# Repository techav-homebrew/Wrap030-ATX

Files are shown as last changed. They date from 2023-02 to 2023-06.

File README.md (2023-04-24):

# Wrap030
Homebrew mATX form-factor 68030 computer

# Memory Map

## Normal Operation
This is the space allocated to each device (even if the device will not use the entire address space allocated, such as the PS/2 keyboard controller which uses no address lines). 

| Device | Start | End | Size |
| --- | --- | --- | --- |
| Main Memory | `$0000,0000`  | `$7fff,ffff`  | 2048MB (256MB available)  |
| Unused (BERR) | `$8000,0000`  | `$cfff,ffff`  | 1280MB |
| Video | `$d000,0000`  | `$d0ff,ffff`  | 16MB |
| Unused (BERR) | `$d100,0000`  | `$d1ff,ffff`  | 16MB |
| ISA Memory | `$d200,0000`  | `$d2ff,ffff`  | 16MB |
| ISA I/O | `$d300,0000`  | `$d3ff,ffff`  | 16MB |
| Unused (BERR) | `$d400,0000`  | `$dbff,ffff`  |  128MB |
| S/P I/O | `$dc00,0000`  | `$dcff,ffff`  | 16MB |
| Reserved (BERR) | `$dd00,0000`  | `$ddff,ffff`  | 16MB |
| Keyboard | `$de00,0000`  | `$deff,ffff`  | 16MB |
| Reserved (BERR) | `$df00,0000`  | `$dfff,ffff`  | 16MB |
| Bus Ctrl Reg | `$e000,0000`  | `$e0ff,ffff`  | 16MB |
| DRAM Ctrl Reg | `$e100,0000`  | `$e1ff,ffff`  | 16MB |
| IRQ Ctrl Reg | `$e200,0000`  | `$e2ff,ffff`  | 16MB |
| Unused (BERR) | `$e300,0000`  | `$efff,ffff`  |  208MB |
| ROM | `$f000,0000`  | `$ffff,ffff`  |  256MB |

## Reset Overlay
The reset overlay allows ROM to be read from the first 256MB of the CPU address space so the CPU can load the proper startup vectors. While the reset overlay is enabled, DRAM is write-only through the first 256MB (the entire DRAM space available on the Wrap030-ATX board). ROM will continue to be readable in its normal address space. This allows the reset vector to point to ROM at its normal address.

The reset overlay is enabled by default on power on. It is disabled by setting the overlay bit on the bus controller register. 

| Device | Start | End | Notes |
| --- | --- | --- | --- |
| ROM Overlay | `$0000,0000`  | `$0fff,ffff`  | Read-only 256MB ROM space |
| DRAM Overlay | `$0000,0000`  | `$0fff,ffff`  | Write-Only 256MB DRAM space |
| DRAM | `$1000,0000`  | `$7fff,ffff`  | Read/Write DRAM space |
| ROM | `$f000,0000`  | `$ffff,ffff`  | Read/Write ROM space |

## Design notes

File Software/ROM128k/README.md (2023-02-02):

This will be a collection of 68k assembly files pulled together to make a single 128kB ROM. Making use of a makefile & linker script to make it easier to build.

## Contents:
1. Reset Vectors
2. TSMON ROM Monitor
3. TSMON Expansion ROM
4. 68k Enhanced BASIC (w/FPU support)

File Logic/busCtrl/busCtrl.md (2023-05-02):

# Wrap030-ATX Bus Controller

## Bus Controller Feature Description

The bus controller handles decoding the CPU Function Codes and Address bus to activate system memory and peripherals. For devices which do not produce their own bus cycle acknowledge signals, it handles timing & wait state generation and produces the appropriate cycle termination signals. It also receives incoming cycle termination signals from other bus devices and reproduces them for the CPU, meeting setup timing requirements. The bus controller generates a bus error for invalid accesses, missing FPU, and bus cycles which time out with no other external device providing an appropriate termination. It will also assert the CPU's cache inhibit signal for peripheral accesses which should not be cached. 

On initial power on, the bus controller will pull the power supply's power on signal low and hold it until the soft power bit in the bus controller register is cleared. 

The bus controller has an internal register accessible at address `$e000,0000` which holds the startup overlay enable bit, soft power control bit, and a general-purpose output for driving an LED.

## Bus Controller Cycles

- DRAM
  - Asserts the RAM chip enable signal and waits for the memory controller to assert its cycle ackowledge signal. 
- ROM
  - Asserts the ROM chip enable signal and the appropriate memory read or write strobe. Inserts wait states for a 70ns ROM and terminates bus cycle.
- Video Controller
  - Asserts the video chip enable signal and waits for the video generator to assert its cycle acknowledge signal.
- ISA
  - Asserts the ISA chip enable signal and waits for the ISA bus controlelr to assert the appropriate 8-bit or 16-bit cycle acknowledge signal.
- Serial/Parallel I/O
  - Asserts the SPIO chip enable signal and the appropriate memory read or write strobe. Inserts wait states for WD16C552 and terminates bus cycle.
- Keyboard Controller
  - Asserts the keyboard controller chip enable signal and waits for the keyboard controller to assert its cycle acknowledge signal.
- DRAM Controller
  - If startup overlay bit is clear:
    - Asserts the DRAM controller chip enable signal and waits for the DRAM controller to assert its cycle acknowledge signal.
  - If startup overlay bit is set:
    - Generates a bus error.
- Bus Controller
  - Reads or writes the bus controller register as appropriate and terminates the bus cycle.
- Interrupt Controller
  - Asserts the interrupt controller chip enable signal and waits for the interrupt controller to assert its cycle acknowledge signal.

## Bus Controller Settings Register
0. Startup Overlay
   - **SET**: Disable startup overlay
   - **CLEAR**: Enable startup overlay
1. Soft Power
   - **SET**: Power down
   - **CLEAR**: Normal operation
2. GPO LED
   - **SET**: LED on
   - **CLEAR**: LED off
3. (future use)
4. (future use)
5. (future use)
6. (future use)
7. (future use)

## Bus Controller State Machine

```mermaid
---
Bus Controller State Machine
---
stateDiagram-v2
    state "Idle" as sIDL
    state idleChoice <<fork>>
    state endFork <<fork>>
    state memChoice <<choice>>

    state "ROM 0" as sROM0
    state "ROM 1" as sROM1
    state "ROM 2" as sROM2
    state "ROM 3" as sROM3
    state "ROM Cycle" as sROM

    state "S/P I/O 0" as sSPIO0
    state "S/P I/O 1" as sSPIO1
    state "S/P I/O 2" as sSPIO2
    state "S/P I/O 3" as sSPIO3
    state "S/P I/O 4" as sSPIO4
    state "S/P I/O 5" as sSPIO5
    state "S/P I/O 6" as sSPIO6
    state "S/P I/O Cycle" as sSPIO

    state "DRAM Hold" as sDRAM0
    state "DRAM Access Cycle" as sDRAM

    state "FPU Start" as sFPU0
    state "FPU Term" as sFPU1
    state "FPU Access Cycle" as sFPU

    state "VidGen Start" as sVID0
    state "VidGen Term" as sVID1
    state "VidGen Access Cycle" as sVID

    state "Keyboard Start" as sKBD0
    state "Keyboard Term" as sKBD1
    state "Keyboard Access Cycle" as sKBD

    state "ISA Start" as sISA0
    state "ISA Term" as sISA1
    state "ISA Access Cycle" as sISA

    state "busCtrl Register Read" as sREGR
    state "busCtrl Register Write" as sREGW
    state regChoice <<choice>>
    state "busCtrl Register Cycle" as sREG
    
    state "IRQ Autovector" as sAVEC

    [*] --> sIDL: sysRESETn = 0
    sIDL --> idleChoice
    idleChoice --> sSPIO
    idleChoice --> sFPU
    idleChoice --> sVID
    idleChoice --> sKBD
    idleChoice --> sISA
    idleChoice --> memChoice
    idleChoice --> sREG
    idleChoice --> sAVEC

    sAVEC --> endFork

    state sREG {
        [*] --> regChoice
        regChoice --> sREGR: cpuRWn = 1
        regChoice --> sREGW: cpuRWn = 0
        sREGR --> [*]
        sREGW --> [*]
    }
    sREG --> endFork

    memChoice --> sDRAM: (overlay = 1 & cpuAddrHi = $00)
    memChoice --> sROM: ((overlay = 0 & cpuAddrHi = $00) | (overlay = 1 & cpuAddrHi = $f0))

    state sISA {
        [*] --> sISA0
        sISA0 --> sISA0: isaACK8n = 1 & isaACK16n = 1
        sISA0 --> sISA1
        sISA1 --> [*]
    }
    sISA --> endFork

    state sKBD {
        [*] --> sKBD0
        sKBD0 --> sKBD0: kbdACKn = 1
        sKBD0 --> sKBD1: kbdACKn = 0
        sKBD1 --> [*]
    }
    sKBD --> endFork

    state sVID {
        [*] --> sVID0
        sVID0 --> sVID0: vidACKn = 1
        sVID0 --> sVID1: vidACKn = 0
        sVID1 --> [*]
    }
    sVID --> endFork
    
    state sDRAM {
        [*] --> sDRAM0
        sDRAM0 --> sDRAM0: ramACKn = 1
        sDRAM0 --> [*]: ramACKn = 0
    }
    sDRAM --> endFork

    state sFPU {
        [*] --> sFPU0
        sFPU0 --> sFPU0: busACKn[0] = 1 & busACKn[1] = 1
        sFPU0 --> sFPU1
        sFPU1 --> [*]
    }
    sFPU --> endFork

    state sROM {
        [*] --> sROM0
        sROM0 --> sROM1
        sROM1 --> sROM2
        sROM2 --> sROM3
        sROM3 --> [*]
    }
    sROM --> endFork

    state sSPIO {
        [*] --> sSPIO0
        sSPIO0 --> sSPIO1
        sSPIO1 --> sSPIO2
        sSPIO2 --> sSPIO3
        sSPIO3 --> sSPIO4
        sSPIO4 --> sSPIO5
        sSPIO5 --> sSPIO6
        sSPIO6 --> [*]
    }
    sSPIO --> endFork
```

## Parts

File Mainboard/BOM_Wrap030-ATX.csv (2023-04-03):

Reference | Value | Footprint | Datasheet | JLC-Part | Mouser-Part | Notes | Sim.Device | Sim.Pins | Socket-Mouser | Qty
SW1 | SW_Push | Button_Switch_THT:SW_PUSH_6mm | ~ |  | 179-TS026660BK260LCR | OFE |  |  |  | 1
C1-C12, C14, C16, C17, C20-C39, C43-C50, C52-C63, C66, C68-C70, C76-C82, C88-C91, C101, C110, C112-C117 | 100nF | Capacitor_SMD:C_0402_1005Metric_Pad0.74x0.62mm_HandSolder | ~ | https://jlcpcb.com/partdetail/1877-CL05B104KO5NNNC/C1525 | 187-CL05B104KO5NNNC | JLC |  |  |  | 78
C13, C15, C18, C19, C40-C42, C51, C64, C65, C67, C92, C111 | 1uF | Capacitor_SMD:C_0402_1005Metric_Pad0.74x0.62mm_HandSolder | ~ | https://jlcpcb.com/partdetail/53938-CL05A105KA5NQNC/C52923 | 187-CL05A105KA5NQNC | JLC |  |  |  | 13
C93-C100 | 2200pF | Capacitor_SMD:C_0402_1005Metric_Pad0.74x0.62mm_HandSolder | ~ | https://jlcpcb.com/partdetail/1883-0402B222K500NT/C1531 | 81-GRM155R71H222KA1J | JLC |  |  |  | 8
C71, C73, C75, C84, C86 | 10uF | Capacitor_THT:CP_Radial_D5.0mm_P2.50mm | ~ |  | 710-860010372001 | OFE |  |  |  | 5
C72, C74, C83, C85, C87 | 100uF | Capacitor_THT:CP_Radial_D7.5mm_P2.50mm | ~ |  | 710-860010473007 | OFE |  |  |  | 5
P1 | AT-P8 | Connector_Molex:Molex_KK-396_A-41791-0006_1x06_P3.96mm_Vertical | ~ |  | 538-26-60-4060 | OFE |  |  |  | 1
P2 | AT-P9 | Connector_Molex:Molex_KK-396_A-41791-0006_1x06_P3.96mm_Vertical | ~ |  | 538-26-60-4060 | OFE |  |  |  | 1
J8 | ATX-24 | Connector_Molex:Molex_Mini-Fit_Jr_5566-24A_2x12_P4.20mm_Vertical | https://www.intel.com/content/dam/www/public/us/en/documents/guides/power-supply-design-guide-june.pdf |  | 538-39-28-8240 |  |  |  |  | 1
J7 | POWER | Connector_PinHeader_2.54mm:PinHeader_1x02_P2.54mm_Vertical | ~ |  | 523-G800NA306018EU | OFE |  |  |  | 1
J9 | RESET | Connector_PinHeader_2.54mm:PinHeader_1x02_P2.54mm_Vertical | ~ |  | 523-G800NA306018EU | OFE |  |  |  | 1
J2 | FPU CLK | Connector_PinHeader_2.54mm:PinHeader_1x03_P2.54mm_Vertical | ~ |  | 523-G800W305018EU | OFE |  |  |  | 1
J10 | BIDEN | Connector_PinHeader_2.54mm:PinHeader_1x03_P2.54mm_Vertical | ~ |  | 523-G800W305018EU | OFE |  |  |  | 1
IDE0 | Conn_02x20_Odd_Even | Connector_PinHeader_2.54mm:PinHeader_2x20_P2.54mm_Vertical | ~ |  | 710-61203921621 | OFE |  |  |  | 1
Y1 | 16M | Crystal:Resonator-3Pin_W7.0mm_H2.5mm | ~ |  | 81-CSTLS16M0X55-B0 | Mouser |  |  |  | 1
D9, D10 | 1N4148W | Diode_SMD:D_SOD-123 |  | https://jlcpcb.com/partdetail/st_semtech-1N4148W/C81598 | 833-1N4148W-TP | JLC | D | 1=K 2=A |  | 2
FID1-FID3 | Fiducial | Fiducial:Fiducial_1mm_Mask2mm | ~ |  |  | NA |  |  |  | 3
D1-D8 | LED | LED_THT:LED_D3.0mm | ~ |  | 859-LTL1CHJETNN | OFE |  |  |  | 8
H1-H9 | 4mm | MountingHole:MountingHole_4mm_Pad_Via | ~ |  |  | NA |  |  |  | 9
X1 | 50M | Oscillator:Oscillator_DIP-8 | http://cdn-reichelt.de/documents/datenblatt/B400/OSZI.pdf |  | 815-ACH-50-EK | Mouser |  |  |  | 1
X2 | 25.175M | Oscillator:Oscillator_DIP-8 | http://cdn-reichelt.de/documents/datenblatt/B400/OSZI.pdf |  | 774-MXO45HS-3C-25.1 | Mouser |  |  |  | 1
X3 | 16M | Oscillator:Oscillator_DIP-8 | http://cdn-reichelt.de/documents/datenblatt/B400/OSZI.pdf |  | 815-ACH-16-EK | Mouser |  |  |  | 1
X4 | 1.8432M | Oscillator:Oscillator_DIP-8 | http://cdn-reichelt.de/documents/datenblatt/B400/OSZI.pdf |  | 520-TCH184-X | Mouser |  |  |  | 1
X5 | 14.3181M | Oscillator:Oscillator_DIP-8 | http://cdn-reichelt.de/documents/datenblatt/B400/OSZI.pdf |  | ECS-2100AX-14.31818MHZ | Mouser |  |  |  | 1
U3 | 74ACT04 | Package_DIP:DIP-14_W7.62mm_Socket | https://assets.nexperia.com/documents/data-sheet/74HC_HCT04.pdf |  | 595-SN74ACT04N | OFE |  |  | 571-1-2199298-3 | 1
U19 | 74ACT139 | Package_DIP:DIP-16_W7.62mm_Socket | http://www.ti.com/lit/ds/symlink/sn74ls139a.pdf |  | 595-CD74ACT139E | OFE |  |  | 571-1-2199298-4 | 1
U24 | ATtiny2313A | Package_DIP:DIP-20_W7.62mm | http://ww1.microchip.com/downloads/en/DeviceDoc/Atmel-2543-AVR-ATtiny2313_Datasheet.pdf |  | 556-ATTINY2313A-PU | Mouser |  |  | 571-1-2199298-6 | 1
U4-U7, U10-U12, U16 | 74ACT245 | Package_DIP:DIP-20_W7.62mm_Socket | http://www.ti.com/lit/gpn/sn74HC245 |  | 595-SN74ACT245N | OFE |  |  | 571-1-2199298-6 | 8
U13-U15 | 74ACT573 | Package_DIP:DIP-20_W7.62mm_Socket | 74xx/74hc573.pdf |  | 595-SN74ACT573N | OFE |  |  | 571-1-2199298-6 | 3
U18 | 74HCT688 | Package_DIP:DIP-20_W7.62mm_Socket | https://www.ti.com/lit/ds/symlink/cd54hc688.pdf |  | 595-CD74HCT688EE4 | OFE |  |  | 571-1-2199298-6 | 1
VRAM1, VRAM2 | CY62256-70PC | Package_DIP:DIP-28_W7.62mm_Socket | https://ecee.colorado.edu/~mcclurel/Cypress_SRAM_CY62256.pdf |  | 972-71256SA15TPG | OFE |  |  | 571-1-2199298-9 | 2
ROM1 | 39SF040 | Package_LCC:PLCC-32_THT-Socket | http://ww1.microchip.com/downloads/en/DeviceDoc/25022B.pdf |  | 804-39SF0407CNHE | OFE |  |  | 575-943224 | 1
U17 | ATF1504AS | Package_LCC:PLCC-44_THT-Socket |  |  | 556-AF1500A10JU | OFE |  |  | 151-1545 | 1
U20 | WD16C552 | Package_LCC:PLCC-68_THT-Socket |  |  | 595-TL16C552AIFN | OFE |  |  | 575-682444 | 1
GLUE1 | ATF1508AS | Package_LCC:PLCC-84_THT-Socket |  |  | 556-ATF1508AS-10JU84 | OFE |  |  | 575-948424 | 1
RAMC1 | ATF1508AS | Package_LCC:PLCC-84_THT-Socket |  |  | 556-ATF1508AS-10JU84 | OFE |  |  | 575-948424 | 1
U32 | ATF1508AS | Package_LCC:PLCC-84_THT-Socket |  |  | 556-ATF1508AS-10JU84 | OFE |  |  | 575-948424 | 1
VGEN1 | ATF1508AS | Package_LCC:PLCC-84_THT-Socket |  |  | 556-ATF1508AS-10JU84 | OFE |  |  | 575-948424 | 1
VBUF1 | ADA4891-4 | Package_SO:SOIC-14_3.9x8.7mm_P1.27mm |  |  | 584-ADA4891-4ARZ | Mouser |  |  |  | 1
U21, U23 | GD65232 | Package_SO:TSSOP-20_4.4x6.5mm_P0.65mm | http://www.ti.com/lit/ds/symlink/gd75232.pdf |  | 595-GD65232PWR | Mouser |  |  |  | 2
U9 | DS1813 | Package_TO_SOT_THT:TO-92_Inline |  |  | 700-DS1813-5T&R | OFE |  |  |  | 1
Q1 | PN2222A | Package_TO_SOT_THT:TO-92L_Inline | ~ |  | 512-PN2222ABU | OFE |  |  |  | 1
R1-R3 | 10k | Resistor_SMD:R_0402_1005Metric_Pad0.72x0.64mm_HandSolder | ~ | https://jlcpcb.com/partdetail/26487-0402WGF1002TCE/C25744 | 303-0402WGF1002TCE | JLC |  |  |  | 3
R4-R12 | 220R | Resistor_SMD:R_0402_1005Metric_Pad0.72x0.64mm_HandSolder | ~ | https://jlcpcb.com/partdetail/25834-0402WGF2200TCE/C25091 | 303-0402WGF2200TCE | JLC |  |  |  | 9
R13-R30, R52-R75 | 1k | Resistor_SMD:R_0402_1005Metric_Pad0.72x0.64mm_HandSolder | ~ | https://jlcpcb.com/partdetail/12256-0402WGF1001TCE/C11702 | 303-0402WGF1001TCE | JLC |  |  |  | 42
R76-R79 | 75R | Resistor_SMD:R_0402_1005Metric_Pad0.72x0.64mm_HandSolder | ~ | https://jlcpcb.com/partdetail/25876-0402WGF750JTCE/C25133 | 303-0402WGF750JTCE | JLC |  |  |  | 4
R31-R51 | 33R | Resistor_SMD:R_0603_1608Metric_Pad0.98x0.95mm_HandSolder | ~ | https://jlcpcb.com/partdetail/23867-0603WAF330JT5E/C23140 | 303-0603WAF330JT5E | JLC |  |  |  | 21
J3 | DE15_Receptacle_HighDensity_MountingHoles | Wrap030-ATX:DE15-HD | https://www.mouser.com/datasheet/2/123/4/EDAC_633_634_Series_D_sub_Connectors_English_Order-2498032.pdf |  | 587-634-015-263-030 | Mouser |  |  |  | 1
J4-J6 | Bus_ISA_16bit | Wrap030-ATX:ISA16 | https://en.wikipedia.org/wiki/Industry_Standard_Architecture |  | 571-5645169-4 | eBay |  |  |  | 3
J14 | L17H26R0121 | Wrap030-ATX:L17H26R0121 |  |  | 523-L17H26R0121 | Mouser |  |  |  | 1
J13 | mDIN-6 | Wrap030-ATX:MiniDIN6 | https://www.te.com/commerce/DocumentDelivery/DDEController?Action=srchrtrv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 |  | 571-5749266-1 | Mouser |  |  |  | 1
U1 | MC68882 | Wrap030-ATX:PGA68 |  |  |  | Mouser |  |  | 437-5108306810061101 | 1
CPU1 | MC68030 | Wrap030-ATX:PGA128 |  |  |  | OFE |  |  | 437-5108712813041101 | 1
U2, U8 | TE-822021-4 | Wrap030-ATX:SIMM72 |  |  | 571-5822021-4 | OFE |  |  |  | 2

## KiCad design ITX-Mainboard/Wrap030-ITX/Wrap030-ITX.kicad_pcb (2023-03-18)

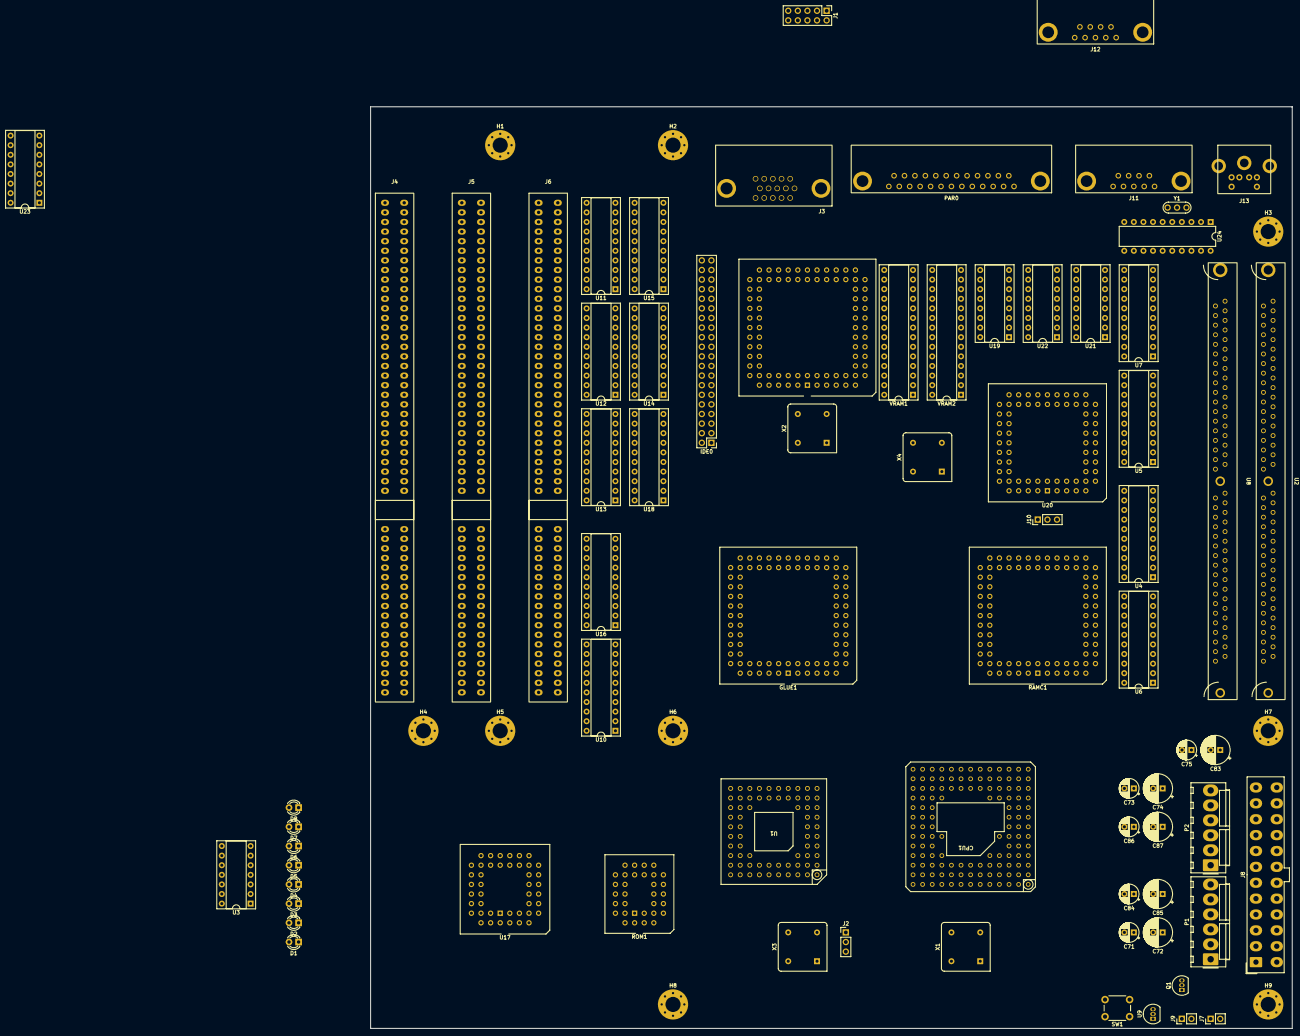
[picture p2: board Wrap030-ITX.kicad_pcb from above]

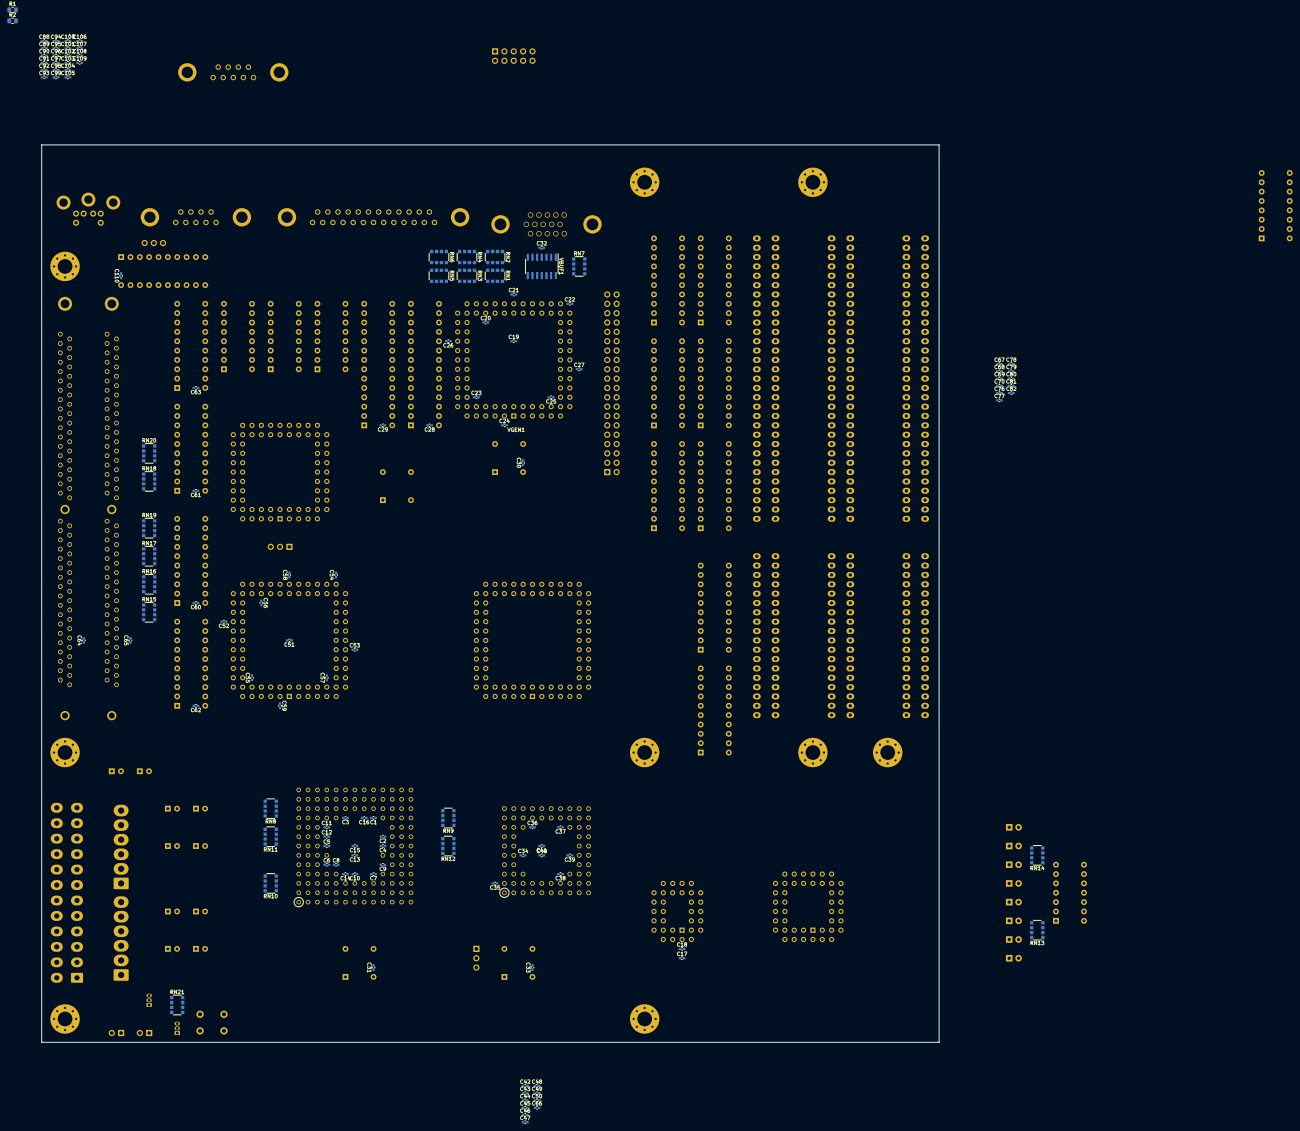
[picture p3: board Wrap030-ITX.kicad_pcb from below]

Board: 2 copper layers, 243.8 x 243.8 mm, 206 parts (124 on the bottom side), 386 nets, no tracks yet.

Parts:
C1, C2, C3, C4, C5, C6, C7, C8, C9, C10, C11, C12, C14, C16, C17, C20, C21, C22, C23, C24, C25, C26, C27, C28, C29, C30, C31, C32, C33, C34, C35, C36, C37, C38, C39, C43, C44, C45, C46, C47, C48, C49, C50, C52, C53, C54, C55, C56, C57, C58, C59, C60, C61, C62, C63, C66, C68, C69, C70, C76, C77, C78, C79, C80, C81, C82, C88, C89, C90, C91, C101, C110: 100nF; C_0402_1005Metric_Pad0.74x0.62mm_HandSolder
C13, C15, C18, C19, C40, C41, C42, C51, C64, C65, C67, C92, C102, C103, C104, C105, C106, C107, C108, C109: 1uF; C_0402_1005Metric_Pad0.74x0.62mm_HandSolder
C71, C73, C75, C84, C86: 10uF; CP_Radial_D5.0mm_P2.50mm
C72, C74, C83, C85, C87: 100uF; CP_Radial_D7.5mm_P2.50mm
C93, C94, C95, C96, C97, C98, C99, C100: 2200pF; C_0402_1005Metric_Pad0.74x0.62mm_HandSolder
CPU1: MC68030; PGA128
D1, D2, D3, D4, D5, D6, D7, D8: LED; LED_D3.0mm
GLUE1: ATF1508AS; PLCC-84_THT-Socket
H1, H2, H3, H4, H5, H6, H7, H8, H9: 4mm; MountingHole_4mm_Pad_Via
IDE0: Conn_02x20_Odd_Even; PinHeader_2x20_P2.54mm_Vertical
J1: Conn_02x05_Odd_Even; PinHeader_2x05_P2.54mm_Vertical
J2, J10: Conn_01x03; PinHeader_1x03_P2.54mm_Vertical
J3: DE15_Receptacle_HighDensity_MountingHoles; DE15-HD
J4, J5, J6: Bus_ISA_16bit; ISA16
J7, J9: Conn_01x02; PinHeader_1x02_P2.54mm_Vertical
J8: ATX-24; Molex_Mini-Fit_Jr_5566-24A_2x12_P4.20mm_Vertical
J11, J12: DE9_Plug_MountingHoles; DE9
J13: DIN-6; MiniDIN6
P1, P2: Conn_01x06; Molex_KK-396_A-41791-0006_1x06_P3.96mm_Vertical
PAR0: DB25_Receptacle_MountingHoles; DB25
Q1: PN2222A; TO-92L_Inline
R1, R2: 10k; R_0805_2012Metric
RAMC1: ATF1508AS; PLCC-84_THT-Socket
RN1, RN2, RN3, RN4, RN5, RN6, RN8, RN9, RN10, RN11, RN12: YC164-FR-071KL; R_Array_Convex_4x1206
RN7: YC164-FR-0775RL; R_Array_Convex_4x1206
RN13, RN14, RN21: YC124-JR-07220RL; R_Array_Convex_4x1206
RN15, RN16, RN17, RN18, RN19, RN20: YC124-JR-1033RL; R_Array_Convex_4x1206
ROM1: SST39SF040; PLCC-32_THT-Socket
SW1: SW_Push; SW_PUSH_6mm
U1: MC68882; PGA68
U2, U8: TE-822021-4; SIMM72
U3: 74HCT04; DIP-14_W7.62mm_Socket
U4, U5, U6, U7, U10, U11, U12: 74HC245; DIP-20_W7.62mm_Socket
U9: DS1813-5+T&R; TO-92_Inline
U13, U14, U15: 74LS573; DIP-20_W7.62mm_Socket
U16: 74AHCT244; DIP-20_W7.62mm_Socket
U17: ATF1504; PLCC-44_THT-Socket
U18: 74HCT688; DIP-20_W7.62mm_Socket
U19: 74LS139; DIP-16_W7.62mm_Socket
U20: WD16C552; PLCC-68_THT-Socket
U21, U22: MAX232; DIP-16_W7.62mm_Socket
U23: 74LS148; DIP-16_W7.62mm_Socket
U24: ATtiny2313A-PU; DIP-20_W7.62mm
VBUF1: ADA4891-4; SOIC-14_3.9x8.7mm_P1.27mm
VGEN1: ATF1508AS; PLCC-84_THT-Socket
VRAM1, VRAM2: CY62256-70PC; DIP-28_W7.62mm_Socket
X1: 50M; Oscillator_DIP-8
X2: 25.175M; Oscillator_DIP-8
X3: 16M; Oscillator_DIP-8
X4: 1.6862M; Oscillator_DIP-8
Y1: 16M; Resonator-3Pin_W7.0mm_H2.5mm

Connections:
+5VP: C75.1, C83.1, J8.9 (+5VSB), RN14.4 (R4.1)
+12V: C71.1, C72.1, J4.9 (+12V), J5.9 (+12V), J6.9 (+12V), J8.10 (+12V), J8.11 (+12V), P1.3
-5V: C86.2, C87.2, J4.5 (-5V), J5.5 (-5V), J6.5 (-5V), P2.3
-12V: C84.2, C85.2, J4.7 (-12V), J5.7 (-12V), J6.7 (-12V), J8.14 (-12V), P1.4
/CPU-FPU/FPU-CLK: J2.3, X3.5 (OUT)
/ISA-IDE/ISA-A0: IDE0.35, J4.62 (BA00), J5.62 (BA00), J6.62 (BA00), U13.19 (Q0)
/ISA-IDE/ISA-A1: IDE0.33, J4.61 (BA01), J5.61 (BA01), J6.61 (BA01), U13.18 (Q1)
/ISA-IDE/ISA-A2: IDE0.36, J4.60 (BA02), J5.60 (BA02), J6.60 (BA02), U13.17 (Q2)
/ISA-IDE/ISA-A3: J4.59 (BA03), J5.59 (BA03), J6.59 (BA03), U13.16 (Q3), U18.2 (P0)
/ISA-IDE/ISA-A4: J4.58 (BA04), J5.58 (BA04), J6.58 (BA04), U13.15 (Q4), U18.4 (P1)
/ISA-IDE/ISA-A5: J4.57 (BA05), J5.57 (BA05), J6.57 (BA05), U13.14 (Q5), U18.6 (P2)
/ISA-IDE/ISA-A6: J4.56 (BA06), J5.56 (BA06), J6.56 (BA06), U13.13 (Q6), U18.8 (P3)
/ISA-IDE/ISA-A7: J4.55 (BA07), J5.55 (BA07), J6.55 (BA07), U13.12 (Q7), U18.11 (P4)
/ISA-IDE/ISA-A8: J4.54 (BA08), J5.54 (BA08), J6.54 (BA08), U14.19 (Q0), U18.13 (P5)
/ISA-IDE/ISA-A9: J4.53 (BA09), J5.53 (BA09), J6.53 (BA09), U14.18 (Q1), U19.2 (A0)
/ISA-IDE/ISA-A10: J4.52 (BA10), J5.52 (BA10), J6.52 (BA10), U14.17 (Q2)
/ISA-IDE/ISA-A11: J4.51 (BA11), J5.51 (BA11), J6.51 (BA11), U14.16 (Q3)
/ISA-IDE/ISA-A12: J4.50 (BA12), J5.50 (BA12), J6.50 (BA12), U14.15 (Q4)
/ISA-IDE/ISA-A13: J4.49 (BA13), J5.49 (BA13), J6.49 (BA13), U14.14 (Q5)
/ISA-IDE/ISA-A14: J4.48 (BA14), J5.48 (BA14), J6.48 (BA14), U14.13 (Q6)
/ISA-IDE/ISA-A15: J4.47 (BA15), J5.47 (BA15), J6.47 (BA15), U14.12 (Q7)
/ISA-IDE/ISA-A16: J4.46 (BA16), J5.46 (BA16), J6.46 (BA16), U15.19 (Q0)
/ISA-IDE/ISA-A17: J4.45 (BA17), J5.45 (BA17), J6.45 (BA17), U15.18 (Q1)
/ISA-IDE/ISA-A18: J4.44 (BA18), J5.44 (BA18), J6.44 (BA18), U15.17 (Q2)
/ISA-IDE/ISA-A19: J4.43 (BA19), J5.43 (BA19), J6.43 (BA19), U15.16 (Q3)
/ISA-IDE/ISA-AEN: J4.28 (ALE), J5.28 (ALE), J6.28 (ALE), U13.1 (OE), U14.1 (OE), U15.1 (OE), U16.1 (1OE), U16.19 (2OE), U17.20 (IO19)
/ISA-IDE/ISA-ALE: J4.42 (AEN), J5.42 (AEN), J6.42 (AEN), U13.11 (Load), U14.11 (Load), U15.11 (Load), U17.21 (IO17)
/ISA-IDE/ISA-CLK: J4.20 (CLK), J5.20 (CLK), J6.20 (CLK), U17.25 (IO35)
/ISA-IDE/ISA-D0: IDE0.3, J4.40 (DB0), J5.40 (DB0), J6.40 (DB0), U11.2 (A0), U12.2 (A0)
/ISA-IDE/ISA-D1: IDE0.5, J4.39 (DB1), J5.39 (DB1), J6.39 (DB1), U11.3 (A1), U12.3 (A1)
/ISA-IDE/ISA-D2: IDE0.7, J4.38 (DB2), J5.38 (DB2), J6.38 (DB2), U11.4 (A2), U12.4 (A2)
/ISA-IDE/ISA-D3: IDE0.9, J4.37 (DB3), J5.37 (DB3), J6.37 (DB3), U11.5 (A3), U12.5 (A3)
/ISA-IDE/ISA-D4: IDE0.11, J4.36 (DB4), J5.36 (DB4), J6.36 (DB4), U11.6 (A4), U12.6 (A4)
/ISA-IDE/ISA-D5: IDE0.13, J4.35 (DB5), J5.35 (DB5), J6.35 (DB5), U11.7 (A5), U12.7 (A5)
/ISA-IDE/ISA-D6: IDE0.15, J4.34 (DB6), J5.34 (DB6), J6.34 (DB6), U11.8 (A6), U12.8 (A6)
/ISA-IDE/ISA-D7: IDE0.17, J4.33 (DB7), J5.33 (DB7), J6.33 (DB7), U11.9 (A7), U12.9 (A7)
/ISA-IDE/ISA-D8: IDE0.4, J4.91 (D8), J5.91 (D8), J6.91 (D8), U10.2 (A0)
/ISA-IDE/ISA-D9: IDE0.6, J4.92 (D9), J5.92 (D9), J6.92 (D9), U10.3 (A1)
/ISA-IDE/ISA-D10: IDE0.8, J4.93 (D10), J5.93 (D10), J6.93 (D10), U10.4 (A2)
/ISA-IDE/ISA-D11: IDE0.10, J4.94 (D11), J5.94 (D11), J6.94 (D11), U10.5 (A3)
/ISA-IDE/ISA-D12: IDE0.12, J4.95 (D12), J5.95 (D12), J6.95 (D12), U10.6 (A4)
/ISA-IDE/ISA-D13: IDE0.14, J4.96 (D13), J5.96 (D13), J6.96 (D13), U10.7 (A5)
/ISA-IDE/ISA-D14: IDE0.16, J4.97 (D14), J5.97 (D14), J6.97 (D14), U10.8 (A6)
/ISA-IDE/ISA-D15: IDE0.18, J4.98 (D15), J5.98 (D15), J6.98 (D15), U10.9 (A7)
/ISA-IDE/ISA-IDE-Connectors/ISA-OSC: J4.30 (OSC), J5.30 (OSC), J6.30 (OSC)
/ISA-IDE/ISA-IDE-Connectors/~IDE-DMACK: IDE0.29, R2.2
/ISA-IDE/ISA-IORDY: IDE0.27, J4.41 (IO_READY), J5.41 (IO_READY), J6.41 (IO_READY), R1.2, U17.29 (IO41)
/ISA-IDE/ISA-LA17: J4.88 (LA17), J5.88 (LA17), J6.88 (LA17), U16.18 (1Y0)
/ISA-IDE/ISA-LA18: J4.87 (LA18), J5.87 (LA18), J6.87 (LA18), U16.16 (1Y1)
/ISA-IDE/ISA-LA19: J4.86 (LA19), J5.86 (LA19), J6.86 (LA19), U16.14 (1Y2)
/ISA-IDE/ISA-LA20: J4.85 (LA20), J5.85 (LA20), J6.85 (LA20), U16.12 (1Y3)
/ISA-IDE/ISA-LA21: J4.84 (LA21), J5.84 (LA21), J6.84 (LA21), U16.3 (2Y0)
/ISA-IDE/ISA-LA22: J4.83 (LA22), J5.83 (LA22), J6.83 (LA22), U16.5 (2Y1)
/ISA-IDE/ISA-LA23: J4.82 (LA23), J5.82 (LA23), J6.82 (LA23), U16.7 (2Y2)
/ISA-IDE/ISA-MASTER: J4.79 (MASTER), J5.79 (MASTER), J6.79 (MASTER), U17.28 (IO40)
/ISA-IDE/ISA-RESET: IDE0.1, J4.2 (RESET), J5.2 (RESET), J6.2 (RESET), U17.19 (IO20)
/ISA-IDE/ISA-SBHE: J4.81 (SBHE), J5.81 (SBHE), J6.81 (SBHE), U17.18 (IO21)
/ISA-IDE/~IDE-CS1: IDE0.37, U19.4 (O0)
/ISA-IDE/~IDE-CS3: IDE0.38, U19.5 (O1)
/ISA-IDE/~ISA-IOCS16: IDE0.32, J4.64 (~IOCS16), J5.64 (~IOCS16), J6.64 (~IOCS16), U17.27 (IO37)
/ISA-IDE/~ISA-IOR: IDE0.25, J4.14 (~IOR), J5.14 (~IOR), J6.14 (~IOR), U17.24 (IO33)
/ISA-IDE/~ISA-IOW: IDE0.23, J4.13 (~IOW), J5.13 (~IOW), J6.13 (~IOW), U17.14 (IO30)
/ISA-IDE/~ISA-MEMCS16: J4.63 (~MEMCS16), J5.63 (~MEMCS16), J6.63 (~MEMCS16), U17.26 (IO36)
/ISA-IDE/~ISA-MEMR: J4.12 (~SMEMR), J4.89 (~MEMR), J5.12 (~SMEMR), J5.89 (~MEMR), J6.12 (~SMEMR), J6.89 (~MEMR), U17.17 (IO24)
/ISA-IDE/~ISA-MEMW: J4.11 (~SMEMW), J4.90 (~MEMW), J5.11 (~SMEMW), J5.90 (~MEMW), J6.11 (~SMEMW), J6.90 (~MEMW), U17.16 (IO25)
/ISA-IDE/~ISA-XFER8: U10.19 (CE), U17.5 (IO14)
/ISA-IDE/~ISA-XFER16: U11.19 (CE), U12.19 (CE), U17.4 (IO16)
/Keyboard/PS2-CLK: J13.5, U24.7 (PD3)
/Keyboard/PS2-DAT: J13.1, U24.8 (PD4)
/Main-Memory/MEM-A0: RAMC1.4 (IO16), RN15.1 (R1.1)
/Main-Memory/MEM-A0R: RN15.8 (R1.2), U2.12 (A0), U8.12 (A0)
/Main-Memory/MEM-A1: RAMC1.22 (IO17), RN15.2 (R2.1)
/Main-Memory/MEM-A1R: RN15.7 (R2.2), U2.13 (A1), U8.13 (A1)
/Main-Memory/MEM-A2: RAMC1.21 (IO19), RN15.3 (R3.1)
/Main-Memory/MEM-A2R: RN15.6 (R3.2), U2.14 (A2), U8.14 (A2)
/Main-Memory/MEM-A3: RAMC1.20 (IO21), RN15.4 (R4.1)
/Main-Memory/MEM-A3R: RN15.5 (R4.2), U2.15 (A3), U8.15 (A3)
/Main-Memory/MEM-A4: RAMC1.18 (IO24), RN16.1 (R1.1)
/Main-Memory/MEM-A4R: RN16.8 (R1.2), U2.16 (A4), U8.16 (A4)
/Main-Memory/MEM-A5: RAMC1.17 (IO25), RN16.2 (R2.1)
/Main-Memory/MEM-A5R: RN16.7 (R2.2), U2.17 (A5), U8.17 (A5)
/Main-Memory/MEM-A6: RAMC1.16 (IO27), RN16.3 (R3.1)
/Main-Memory/MEM-A6R: RN16.6 (R3.2), U2.18 (A6), U8.18 (A6)
/Main-Memory/MEM-A7: RAMC1.15 (IO29), RN16.4 (R4.1)
/Main-Memory/MEM-A7R: RN16.5 (R4.2), U2.28 (A7), U8.28 (A7)
/Main-Memory/MEM-A8: RAMC1.31 (IO35), RN17.1 (R1.1)
/Main-Memory/MEM-A8R: RN17.8 (R1.2), U2.31 (A8), U8.31 (A8)
/Main-Memory/MEM-A9: RAMC1.30 (IO37), RN17.2 (R2.1)
/Main-Memory/MEM-A9R: RN17.7 (R2.2), U2.32 (A9), U8.32 (A9)
/Main-Memory/MEM-A10: RAMC1.29 (IO38), RN17.3 (R3.1)
/Main-Memory/MEM-A10R: RN17.6 (R3.2), U2.19 (A10), U8.19 (A10)
/Main-Memory/MEM-A11: RAMC1.28 (IO40), RN17.4 (R4.1)
/Main-Memory/MEM-A11R: RN17.5 (R4.2), U2.29 (A11), U8.29 (A11)
/Main-Memory/MEM-D0: U2.2 (D0), U4.2 (A0), U8.2 (D0)
/Main-Memory/MEM-D1: U2.4 (D1), U4.3 (A1), U8.4 (D1)
/Main-Memory/MEM-D2: U2.6 (D2), U4.4 (A2), U8.6 (D2)
/Main-Memory/MEM-D3: U2.8 (D3), U4.5 (A3), U8.8 (D3)
/Main-Memory/MEM-D4: U2.20 (D4), U4.6 (A4), U8.20 (D4)
/Main-Memory/MEM-D5: U2.22 (D5), U4.7 (A5), U8.22 (D5)
/Main-Memory/MEM-D6: U2.24 (D6), U4.8 (A6), U8.24 (D6)
/Main-Memory/MEM-D7: U2.26 (D7), U4.9 (A7), U8.26 (D7)
/Main-Memory/MEM-D8: U2.49 (D8), U5.2 (A0), U8.49 (D8)
/Main-Memory/MEM-D9: U2.51 (D9), U5.3 (A1), U8.51 (D9)
/Main-Memory/MEM-D10: U2.53 (D10), U5.4 (A2), U8.53 (D10)
/Main-Memory/MEM-D11: U2.55 (D11), U5.5 (A3), U8.55 (D11)
/Main-Memory/MEM-D12: U2.57 (D12), U5.6 (A4), U8.57 (D12)
/Main-Memory/MEM-D13: U2.61 (D13), U5.7 (A5), U8.61 (D13)
/Main-Memory/MEM-D14: U2.63 (D14), U5.8 (A6), U8.63 (D14)
/Main-Memory/MEM-D15: U2.65 (D15), U5.9 (A7), U8.65 (D15)
/Main-Memory/MEM-D16: U2.3 (D16), U6.2 (A0), U8.3 (D16)
/Main-Memory/MEM-D17: U2.5 (D17), U6.3 (A1), U8.5 (D17)
/Main-Memory/MEM-D18: U2.7 (D18), U6.4 (A2), U8.7 (D18)
/Main-Memory/MEM-D19: U2.9 (D19), U6.5 (A3), U8.9 (D19)
/Main-Memory/MEM-D20: U2.21 (D20), U6.6 (A4), U8.21 (D20)
/Main-Memory/MEM-D21: U2.23 (D21), U6.7 (A5), U8.23 (D21)
/Main-Memory/MEM-D22: U2.25 (D22), U6.8 (A6), U8.25 (D22)
/Main-Memory/MEM-D23: U2.27 (D23), U6.9 (A7), U8.27 (D23)
/Main-Memory/MEM-D24: U2.50 (D24), U7.2 (A0), U8.50 (D24)
/Main-Memory/MEM-D25: U2.52 (D25), U7.3 (A1), U8.52 (D25)
/Main-Memory/MEM-D26: U2.54 (D26), U7.4 (A2), U8.54 (D26)
/Main-Memory/MEM-D27: U2.56 (D27), U7.5 (A3), U8.56 (D27)
/Main-Memory/MEM-D28: U2.58 (D28), U7.6 (A4), U8.58 (D28)
/Main-Memory/MEM-D29: U2.60 (D29), U7.7 (A5), U8.60 (D29)
/Main-Memory/MEM-D30: U2.62 (D30), U7.8 (A6), U8.62 (D30)
/Main-Memory/MEM-D31: U2.64 (D31), U7.9 (A7), U8.64 (D31)
/Main-Memory/~MEM-CAS0R: RN18.8 (R1.2), U2.40 (~CAS0), U8.40 (~CAS0)
/Main-Memory/~MEM-CAS0: RAMC1.40 (IO51), RN18.1 (R1.1)
/Main-Memory/~MEM-CAS1R: RN18.7 (R2.2), U2.43 (~CAS1), U8.43 (~CAS1)
/Main-Memory/~MEM-CAS1: RAMC1.39 (IO53), RN18.2 (R2.1)
/Main-Memory/~MEM-CAS2R: RN18.6 (R3.2), U2.41 (~CAS2), U8.41 (~CAS2)
/Main-Memory/~MEM-CAS2: RAMC1.37 (IO56), RN18.3 (R3.1)
/Main-Memory/~MEM-CAS3R: RN18.5 (R4.2), U2.42 (~CAS3), U8.42 (~CAS3)
/Main-Memory/~MEM-CAS3: RAMC1.36 (IO57), RN18.4 (R4.1)
/Main-Memory/~MEM-RAS0R: RN19.8 (R1.2), U2.34 (~RAS2), U2.44 (~RAS0)
/Main-Memory/~MEM-RAS0: RAMC1.27 (IO43), RN19.1 (R1.1)
/Main-Memory/~MEM-RAS1R: RN19.7 (R2.2), U2.33 (~RAS3), U2.45 (~RAS1)
/Main-Memory/~MEM-RAS1: RAMC1.25 (IO45), RN19.2 (R2.1)
/Main-Memory/~MEM-RAS2R: RN19.6 (R3.2), U8.34 (~RAS2), U8.44 (~RAS0)
/Main-Memory/~MEM-RAS2: RAMC1.24 (IO46), RN19.3 (R3.1)
/Main-Memory/~MEM-RAS3R: RN19.5 (R4.2), U8.33 (~RAS3), U8.45 (~RAS1)
/Main-Memory/~MEM-RAS3: RAMC1.41 (IO49), RN19.4 (R4.1)
/Main-Memory/~MEM-WER: RN20.8 (R1.2), U2.47 (~WE), U8.47 (~WE)
/Main-Memory/~MEM-WE: RAMC1.35 (IO59), RN20.1 (R1.1), U4.1 (A->B), U5.1 (A->B), U6.1 (A->B), U7.1 (A->B)
/Power-Supply/PWR_ON_R: Q1.2 (B), RN21.8 (R1.2)
/Power-Supply/~PWR_ON: J7.2, J8.16 (PS_ON#), Q1.3 (C)
/Serial-Parallel-IO/COM0-C1M: C102.2, U21.3 (C1-)
/Serial-Parallel-IO/COM0-C1P: C102.1, U21.1 (C1+)
/Serial-Parallel-IO/COM0-C2M: C103.1, U21.5 (C2-)
/Serial-Parallel-IO/COM0-C2P: C103.2, U21.4 (C2+)
/Serial-Parallel-IO/COM0-CTS232: J11.8, U21.8 (R2IN)
/Serial-Parallel-IO/COM0-RTS232: J11.7, U21.7 (T2OUT)
/Serial-Parallel-IO/COM0-RX232: J11.2, U21.13 (R1IN)
/Serial-Parallel-IO/COM0-SIN: U20.41 (SIN0), U21.12 (R1OUT)
/Serial-Parallel-IO/COM0-SOUT: U20.26 (SOUT0), U21.11 (T1IN)
/Serial-Parallel-IO/COM0-TX232: J11.3, U21.14 (T1OUT)
/Serial-Parallel-IO/COM0-VM: C105.1, U21.6 (VS-)
/Serial-Parallel-IO/COM0-VP: C104.1, U21.2 (VS+)
/Serial-Parallel-IO/COM1-C1M: C106.2, U22.3 (C1-)
/Serial-Parallel-IO/COM1-C1P: C106.1, U22.1 (C1+)
/Serial-Parallel-IO/COM1-C2M: C109.1, U22.5 (C2-)
/Serial-Parallel-IO/COM1-C2P: C109.2, U22.4 (C2+)
/Serial-Parallel-IO/COM1-CTS232: J12.8, U22.8 (R2IN)
/Serial-Parallel-IO/COM1-RTS232: J12.7, U22.7 (T2OUT)
/Serial-Parallel-IO/COM1-RX232: J12.2, U22.13 (R1IN)
/Serial-Parallel-IO/COM1-SIN: U20.62 (SIN1), U22.12 (R1OUT)
/Serial-Parallel-IO/COM1-SOUT: U20.10 (SOUT1), U22.11 (T1IN)
/Serial-Parallel-IO/COM1-TX232: J12.3, U22.14 (T1OUT)
/Serial-Parallel-IO/COM1-VM: C108.1, U22.6 (VS-)
/Serial-Parallel-IO/COM1-VP: C107.1, U22.2 (VS+)
/Serial-Parallel-IO/PAR-BIDEN: J10.2, U20.1 (BIDEN)
/Serial-Parallel-IO/PAR-BUSY: PAR0.11, U20.66 (BUSY)
/Serial-Parallel-IO/PAR-D0: C93.1, U20.53 (PD0)
/Serial-Parallel-IO/PAR-D0-C: C93.2, PAR0.2
/Serial-Parallel-IO/PAR-D1: C94.1, U20.52 (PD1)
/Serial-Parallel-IO/PAR-D1-C: C94.2, PAR0.3
/Serial-Parallel-IO/PAR-D2: C95.1, U20.51 (PD2)
/Serial-Parallel-IO/PAR-D2-C: C95.2, PAR0.4
/Serial-Parallel-IO/PAR-D3: C96.1, U20.50 (PD3)
/Serial-Parallel-IO/PAR-D3-C: C96.2, PAR0.5
/Serial-Parallel-IO/PAR-D4: C97.1, U20.49 (PD4)
/Serial-Parallel-IO/PAR-D4-C: C97.2, PAR0.6
/Serial-Parallel-IO/PAR-D5: C98.1, U20.48 (PD5)
/Serial-Parallel-IO/PAR-D5-C: C98.2, PAR0.7
/Serial-Parallel-IO/PAR-D6: C99.1, U20.47 (PD6)
/Serial-Parallel-IO/PAR-D6-C: C99.2, PAR0.8
/Serial-Parallel-IO/PAR-D7: C100.1, U20.46 (PD7)
/Serial-Parallel-IO/PAR-D7-C: C100.2, PAR0.9
/Serial-Parallel-IO/PAR-PE: PAR0.12, U20.67 (PE)
/Serial-Parallel-IO/PAR-SLCT: PAR0.13, U20.65 (SLCT)
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

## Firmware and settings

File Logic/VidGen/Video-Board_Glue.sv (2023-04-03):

/******************************************************************************
 * Wrap030 Video Generator Logic
 * techav
 * 2022-12-16
 ******************************************************************************
 * 2022-12-26 changed vram address calculation to an address counter to reduce
 *            macrocell utilization.
 * 2022-12-27 added logic to deassert nCpuDSACK when the CPU deasserts either
 *            nCpuDS or nCpuCE, to reduce the risk of interfering with the
 *            CPU's next bus transaction, as recommended in Section 7 of the
 *            68030 manual.
 * 2022-12-29 rework vram sequencer to improve efficiency because fitter fails
 *            after setting pin assignments to match schematic
 * 2022-12-31 fixed logic bugs in the vram address counter which prevented the
 *            entire frame from being drawn, and prevented modes 1 & 3 from 
 *            properly displaying the full vertical resolution.
 *            fixed logic bug preventing CPU accesses during blanking periods.
 *****************************************************************************/

module vidGen (
    input   wire                nReset,     // primary system reset         1
    input   wire                pixClk,     // primary video pixel clock    83
    input   wire                nCpuCE,     // cpu bus chip enable signal   84
    output  wire                nVramWr,    // vram bus write strobe        12
    output  wire [14:0]         vramAddr,   // vram bus address signals
    input   wire                nCpuDS,     // cpu bus data strobe          6
    inout   wire                nCpuDSACK,  // cpu data strobe acknowledge  5
    output  wire                nVramRd,    // vram bus read strobe         22
    inout   wire [7:0]          vramData,   // vram bus data signals
    output  wire                nVramCE0,   // vram bus chip 0 enable       29
    output  wire                nVramCE1,   // vram bus chip 1 enable       44
    input   wire                cpuRnW,     // cpu bus read/write signal    41
    output  wire [3:0]          vidOut,     // video RGBI output            45,49,51,46
    output  wire                vidV,       // video VSync output           48
    output  wire                vidH,       // video HSync output           50
    inout   wire [7:0]          cpuData,    // cpu bus data signals
    input   wire [15:0]         cpuAddr     // cpu bus address signals
);

// we're going with 640x400@70Hz, from 25.175MHz pixel clock
parameter H_TOTAL = 800;
parameter H_VIS = 640;
parameter H_FRONT = 16;
parameter H_SYNC = 96;
parameter H_BACK = 48;

parameter V_TOTAL = 449;
parameter V_VIS = 400;
parameter V_FRONT = 12;
parameter V_SYNC = 2;
parameter V_BACK = 35;

// these are our configuration registers
reg [1:0]   rVidMode    = 0;    // select from the 4 different video modes
reg         rBufSel     = 0;    // video modes 0 & 2 can be double-buffered
reg         rVidBlank   = 0;    // 0: video enabled; 1: video blanked

// set up our h/v sync counters
reg [9:0] hCount;
reg [8:0] vCount;
always @(negedge pixClk or negedge nReset) begin
    if(!nReset) begin
        hCount <= 0;
        vCount <= 0;
    end else begin
        if(hCount == H_TOTAL-1) begin
            hCount <= 0;
            if(vCount == V_TOTAL-1) begin
                vCount <= 0;
            end else begin
                vCount <= vCount + 9'h1;
            end
        end else begin
            hCount <= hCount + 10'h1;
        end
    end
end
// h sync pulse (neg)
always @(posedge pixClk or negedge nReset) begin
    if(!nReset) begin
        vidH <= 1;
    end else begin
        if(hCount >= (H_VIS+H_FRONT+2) && hCount < (H_VIS+H_FRONT+H_SYNC+2)) begin
            // hSync pulse is offset by 2 clocks to account for the offset
            // introduced through loading data from VRAM
            vidH <= 0;
        end else begin
            vidH <= 1;
        end
    end
end
// v sync pulse (pos)
always @(posedge pixClk or negedge nReset) begin
    if(!nReset) begin
        vidV <= 0;
    end else begin
        if(vCount >= (V_VIS+V_FRONT) && vCount < (V_VIS+V_FRONT+V_SYNC)) begin
            vidV <= 1;
        end else begin
            vidV <= 0;
        end
    end
end

wire vidActive;
assign vidActive = (hCount < H_VIS+2) & (hCount >= 2) & (vCount < V_VIS);

reg [7:0] vReadData;    // store video data read from VRAM
reg cpuReadInProgress;  // keep track of when we're actively servicing a CPU read request
reg [15:0] vReadAddr;   // VRAM video address counter
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

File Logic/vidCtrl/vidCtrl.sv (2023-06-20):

module vidCtrl (
    input   wire                nReset,     // primary system reset         1
    input   wire                pixClk,     // primary video pixel clock    83
    input   wire                nCpuCE,     // cpu bus chip enable signal   84
    output  reg                 nVramWr,    // vram bus write strobe        12
    output  reg  [14:0]         vramAddr,   // vram bus address signals
    input   wire                nCpuDS,     // cpu bus data strobe          6
    output  reg                 nCpuDSACK,  // cpu data strobe acknowledge  5
    output  reg                 nVramRd,    // vram bus read strobe         22
    inout   wire [7:0]          vramData,   // vram bus data signals
    output  reg                 nVramCE0,   // vram bus chip 0 enable       29
    output  reg                 nVramCE1,   // vram bus chip 1 enable       44
    input   wire                cpuRnW,     // cpu bus read/write signal    41
    output  reg  [3:0]          vidOut,     // video RGBI output            45,49,51,46
    output  reg                 vidV,       // video VSync output           48
    output  reg                 vidH,       // video HSync output           50
    inout   wire [7:0]          cpuData,    // cpu bus data signals
    input   wire [15:0]         cpuAddr     // cpu bus address signals
);

// outputting 640x480@60Hz frame from 25.175MHx pixel clock
// displaying 256x240 video at 4bpp
parameter H_TOTAL   =   800;
parameter H_VIS     =   512;
parameter H_BLACK0  =    64;
parameter H_FRONT   =    16;
parameter H_SYNC    =    96;
parameter H_BACK    =    46;
parameter H_BLACK1  =    64;

parameter V_TOTAL   =   525;
parameter V_VIS     =   480;
parameter V_FRONT   =    10;
parameter V_SYNC    =     2;
parameter V_BACK    =    33;

// set up H/V sync counters
reg [9:0] hCount;
reg [9:0] vCount;
always @(negedge pixClk or negedge nReset) begin
    if(!nReset) begin
        hCount <= 0;
        vCount <= 0;
    end else begin
        if(hCount == H_TOTAL-1) begin
            hCount <= 0;
            if(vCount == V_TOTAL-1) begin
                vCount <= 0;
            end else begin
                vCount <= vCount + 10'h1;
            end
        end else begin
            hCount <= hCount + 10'h1;
        end
    end
end
// h sync pulse (neg)
always @(posedge pixClk or negedge nReset) begin
    if(!nReset) begin
        vidH <= 1;
    end else begin
        if(hCount >= (H_VIS+H_BLACK0+H_FRONT+2) 
            && hCount < (H_VIS+H_BLACK0+H_FRONT+H_SYNC+2)) begin
                vidH <= 0;
        end else begin
            vidH <= 1;
        end
    end
end
// v sync pulse (neg)
always @(posedge pixClk or negedge nReset) begin
    if(!nReset) begin
        vidV <= 1;
    end else begin
        if(vCount >= (V_VIS+V_FRONT) && vCount < (V_VIS+V_FRONT+V_SYNC)) begin
            vidV <= 0;
        end else begin
            vidV <= 1;
        end
    end
end

wire vidActive, cpuTime;
assign vidActive = (hCount < H_VIS) & (vCount < V_VIS);
assign cpuTime = ((vidActive && hCount[1]) || !vidActive);

// VRAM address bus
always @(posedge pixClk) begin
    if(vidActive && hCount[1:0] == 0) begin
        // time for a video data fetch
        vramAddr[14:7] = vCount[8:1];
        vramAddr[6:0] = hCount[8:2];
    end else if(cpuTime && cpuRequest) begin
        // we have space here for a CPU cycle if needed
        vramAddr = cpuAddr[14:0];
    end else begin
        // nothing needs the VRAM bus, so we don't care what the VRAM address is
        vramAddr = vramAddr;
    end
end

// VRAM data bus
always @(posedge pixClk) begin
    if(cpuTime && cpuState == cWR1) begin
        vramData <= cpuDataReg;
    end else begin
        vramData <= 8'bZZZZZZZZ;
    end
end

// VRAM chip enable signals
always @(posedge pixClk, negedge nReset) begin
    if(!nReset) begin
        nVramCE0 <= 1;
        nVramCE1 <= 1;
    end else begin
        if(vidActive && hCount[1:0] == 0) begin
            nVramCE0 <= vidBufSel;
            nVramCE1 <= ~vidBufSel;
        end else if(cpuTime && cpuRequest) begin
            nVramCE0 <= cpuAddr[15];
            nVramCE1 <= ~cpuAddr[15];
        end else begin
            nVramCE0 <= 1;
            nVramCE1 <= 1;
        end
    end
end

// VRAM read strobe
always @(posedge pixClk, negedge nReset) begin
    if(!nReset) begin
        nVramRd <= 1;
    end else begin
        if(vidActive && hCount[1:0] == 0) begin
            nVramRd <= 0;
        end else if(cpuTime && cpuState == cRD0) begin
            nVramRd <= 0;
        end else begin
            nVramRd <= 1;
        end
    end
end

// VRAM write strobe
always @(posedge pixClk, negedge nReset) begin
    if(!nReset) begin
        nVramWr <= 1;
    end else begin
        if(cpuTime && cpuState == cWR1) begin
            nVramWr <= 0;
        end else begin
            nVramWr <= 1;
        end
    end
end

// video data latch
reg [7:0] vidDataReg;
always @(posedge pixClk, negedge nReset) begin
    if(!nReset) begin
        vidDataReg <= 0;
    end else begin
        if(vidActive && hCount[1:0] == 1) begin
            vidDataReg <= vramData;
        end
    end
end

// video output
always @(negedge pixClk, negedge nReset) begin
    if(!nReset) begin
        vidOut <= 0;
    end else begin
        if(vidActive && (hCount[1] ^ hCount[0])) begin
            vidOut <= vidDataReg[7:4];
        end else if(vidActive && ~(hCount[1] ^ hCount[0])) begin
            vidOut <= vidDataReg[3:0];
        end else begin
            vidOut <= 0;
        end
    end
end

// CPU cycle service


wire cpuRequest, cpuAck;
assign cpuRequest = (cpuState == cWR1 || cpuState == cRD0);
assign cpuAck = cpuRequest & cpuTime;

// CPU cycle state machine
parameter
    cIDL    =   0,
    cWR0    =   1,
    cWR1    =   2,
    cRD0    =   3,
    cRD1    =   4,
    cRGW    =   5,  // register write
    cRGR    =   6;  // register read
reg [2:0] cpuState;
wire [2:0] cpuNextState;

always @(posedge pixClk, negedge nReset) begin
    if(!nReset) begin
        cpuState <= cIDL;
    end else begin
        cpuState <= cpuNextState;
    end
end
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

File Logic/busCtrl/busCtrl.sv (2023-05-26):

module busCtrl (
    // general system signals
    input   wire            sysClk,         // Primary system clock
    input   wire            sysRESETn,      // Primary system reset signal
    input   wire            sysPWROKn,      // System power on OK signal
    output  wire            sysPRWONn,      // System ATX soft power on latch
    output  wire            sysMWRn,        // System memory write strobe
    output  wire            sysMRDn,        // System memory read strobe
    output  wire            sysLEDdebug,    // GPIO for software-controlled LED
    input   wire [1:0]      sysACKn,        // System generic cycle acknowledge
    // CPU control signals
    inout   wire [7:0]      cpuDataHiHi,    // CPU data bus D[31:24]
    input   wire [10:0]     cpuAddrHi,      // CPU addr bus A[31:21]
    input   wire [3:0]      cpuAddrMid,     // CPU addr bus A[19:16]
    input   wire [1:0]      cpuAddrLo,      // CPU addr bus A[1:0]
    input   wire [2:0]      cpuFC,          // CPU function code FC[2:0]
    input   wire            cpuDSn,         // CPU data strobe
    input   wire            cpuASn,         // CPU address strobe
    input   wire            cpuRWn,         // CPU read/write signal
    input   wire [1:0]      cpuSIZ,         // CPU size signals
    inout   wire [1:0]      cpuDSACKn,      // CPU async cycle acknowledge signals
    input   wire            cpuSTERMn,      // CPU sync cycle acknowledge signals
    output  wire            cpuAVECn,       // CPU autovector signal
    output  wire            cpuBERRn,       // CPU bus error signal
    output  wire            cpuCIINn,       // CPU cache inhibit signal
    // FPU signals
    input   wire            fpuSENSEn,      // FPU presence detect signal
    output  reg             fpuCEn,         // FPU chip enable
    // General peripheral signals
    output  reg             romCEn,         // ROM chip enable
    output  reg             vidCEn,         // Video chip enable
    input   wire            vidACKn,        // Video cycle acknowledge
    output  wire            keyATNn,        // Keyboard chip enable
    input   wire            keyACKn,        // Keyboard cycle acknowledge
    output  reg             spioCEn,        // Serial/Parallel chip enable
    output  reg             isaCEn,         // ISA chip enable
    input   wire            isaACK8n,       // ISA 8-bit cycle acknowledge
    input   wire            isaACK16n,      // ISA 16-bit cycle acknoledge
    output  reg             ramCEn,         // RAM chip enable
    input   wire            ramACKn         // RAM cycle acknowledge
);

// control registers
reg regOverlay, regPower, regGPIO;

// primary bus controller state machine
parameter
    sIDLE   =    0, // Idle state
    sROM0   =    1, // ROM state 0
    sROM1   =    2, // ROM state 1
    sROM2   =    3, // ROM state 2
    sROM3   =    4, // ROM state 3
    sSPI0   =    5, // SPIO state 0
    sSPI1   =    6, // SPIO state 1
    sSPI2   =    7, // SPIO state 2
    sSPI3   =    8, // SPIO state 3
    sSPI4   =    9, // SPIO state 4
    sSPI5   =   10, // SPIO state 5
    sSPI6   =   11, // SPIO state 6
    sDRAM   =   12, // DRAM access cycle
    sAVEC   =   13, // IRQ Autovector cycle
    sFPU0   =   14, // FPU access start
    sFPU1   =   15, // FPU access termination
    sBERR   =   16, // Bus Error state
    sVID0   =   17, // vidGen access start
    sVID1   =   18, // vidGen access termination
    sKBD0   =   19, // keyboard access start
    sKBD1   =   20, // keyboard access termination
    sISA0   =   21, // ISA access start
    sISA1   =   22, // ISA access termination
    sREGR   =   23, // busCtrl register read
    sREGW   =   24, // busCtrl register write
    sEXT    =   25; // external access cycle
reg [4:0] timingState, nextState;

always @(posedge sysClk, negedge sysRESETn) begin
    if(!sysRESETn) begin
        timingState <= sIDLE;
    end else begin
        timingState <= nextState;
    end 
end

always_comb begin
    nextState = timingState;
    case(timingState)
        sIDLE: begin
            if(!cpuASn) begin
                if(cpuFC == 3'b111) begin
                    // CPU space 
                    if(cpuAddrHi == 11'h7ff & cpuAddrMid == 4'hf) begin
                        // IRQ cycle
                        // we'll handle these with AVEC until IRQ controller is ready
                        nextState = sAVEC;
                    end else if(cpuAddrHi == 0 & cpuAddrMid == 4'h2) begin
                        // coprocessor access cycle
                        if(!fpuSENSEn) nextState = sFPU0;
                        else nextState = sBERR;
                    end else begin
                        // unsupported CPU space cycle
                        nextState = sBERR;
                    end
                end else begin
                    // memory space
                    if(cpuAddrHi[10:9] == 0) begin
                        // DRAM space or overlay ROM read
                        if(!regOverlay & cpuRWn) nextState = sROM0;
                        else nextState = sDRAM;
                    end else begin
                        case(cpuAddrHi[10:3])
                            /*8'h00: begin
                                // DRAM space or overlay ROM read
                                if(!regOverlay & cpuRWn) nextState = sROM0;
                                else nextState = sDRAM;
                            end*/
                            8'hf0: nextState = sROM0;
                            8'hd0: nextState = sVID0;
                            8'hd2, 8'hd3: nextState = sISA0;
                            8'hdc: nextState = sSPI0;
                            8'hde: nextState = sKBD0;
                            8'he0: begin
                                if(cpuRWn) nextState = sREGR;
                                else nextState = sREGW;
                            end
                            default: nextState = sEXT;
                        endcase 
                    end
                end
            end else begin
                nextState = sIDLE;
            end
        end
        
        // ROM sequence
        sROM0: nextState = sROM1;
        sROM1: nextState = sROM2;
        sROM2: nextState = sROM3;

        // SPIO sequence
        sSPI0: nextState = sSPI1;
        sSPI1: nextState = sSPI2;
        sSPI2: nextState = sSPI3;
        sSPI3: nextState = sSPI4;
        sSPI4: nextState = sSPI5;
        sSPI5: nextState = sSPI6;

        // FPU sequence
        //sFPU0: nextState = sFPU1;

        // vidGen sequence
        sVID0: nextState = sVID1;

        // keyboard controller sequence
        sKBD0: nextState = sKBD1;

        // ISA sequence
        sISA0: nextState = sISA1;
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

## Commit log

2021-12-02 Add BOM
    [BillOfMaterials.csv]
2021-12-29 New Verilog glue logic
    [BillOfMaterials.csv]
2021-12-30 Add option to skip chip erase
    [srecLoadWin.py]
2021-12-30 Change UART to 38400bps
2021-12-31 TSMON 2nd UART
2021-12-31 Add 2nd UART to BASIC
2022-01-16 Shorten BASIC loader delays
    [bas.py]
2022-10-29 Mezzanine glue fpu draft
2022-12-24 Video Board Initial Schematic & Gerbers
    [Video-Board_copper_bottom.gbr, Video-Board_copper_top.gbr, Video-Board_drill_1_16.xln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]
2022-12-25 Video Board logic first draft
2022-12-28 DSACK deassertion logic fix
    [Video-Board_Glue.sv]
2023-01-02 FPU glue logic debugging
2023-03-16 Begin Schematic Unification
    [Bus-Ctrl.kicad_sch, MainMem.kicad_sch, ROM.kicad_sch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]
2023-03-18 Schematic substantial completion
    [Bus-Ctrl.kicad_sch, ISA-IDE-Con.kicad_sch, ISA-IDE.kicad_sch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]
2023-03-23 PCB substantial completion
    [Bus-Ctrl.kicad_sch, ISA-IDE-Con.kicad_sch, ISA-IDE.kicad_sch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]
2023-03-24 Add interrupt controller to schematic
    [Bus-Ctrl.kicad_sch, IRQ.kicad_sch, ISA-IDE-Con.kicad_sch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]
2023-03-26 Completing PCB Routing
    [Bus-Ctrl.kicad_sch, IRQ.kicad_sch, ISA-IDE-Con.kicad_sch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]
2023-03-28 PCB Silkscreen & DRC Cleanup
    [Bus-Ctrl.kicad_sch, ISA-IDE.kicad_sch, MainMem.kicad_sch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]
2023-03-30 Initial production files
    [BOM_Wrap030.xlsx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]
2023-03-30 initial production schematic
    [ISA-IDE-Con.kicad_sch, SPIO.kicad_sch, cpu-fpu.kicad_sch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]
2023-03-31 Replace resistor nets with 0402 & update gerbers
    [BOM_Wrap030-ITX.csv, BOM_Wrap030.xlsx, Bus-Ctrl.kicad_sch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]
2023-04-03 Rebase around new mATX mainboard
    [BOM_Wrap030-ATX.csv, BOM_Wrap030-ITX.csv, BOM_Wrap030.xlsx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]
2023-05-05 fix address decoding bug in busCtrl logic
    [busCtrl.sv]
2023-05-19 fix DRAM controller settings register
    [dramCtrl.sv]
2023-05-23 3-state busCtrl DSACKx wired-or with FPU DSACKx
2023-05-26 Fix startup overlay reset & soft power on
    [busCtrl.sv]
2023-05-26 add soft power off control to TSMON
